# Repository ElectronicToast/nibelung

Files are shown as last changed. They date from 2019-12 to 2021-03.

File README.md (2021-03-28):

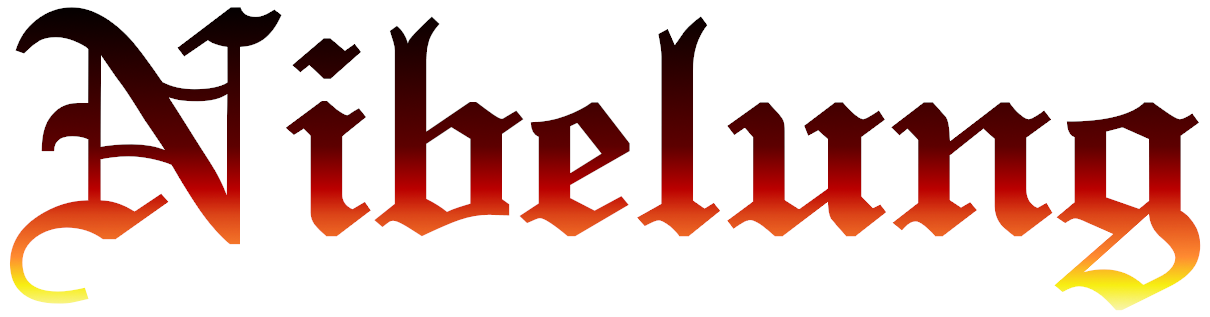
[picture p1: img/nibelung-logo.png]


 

Teensy 4.0-based RGB LED controller

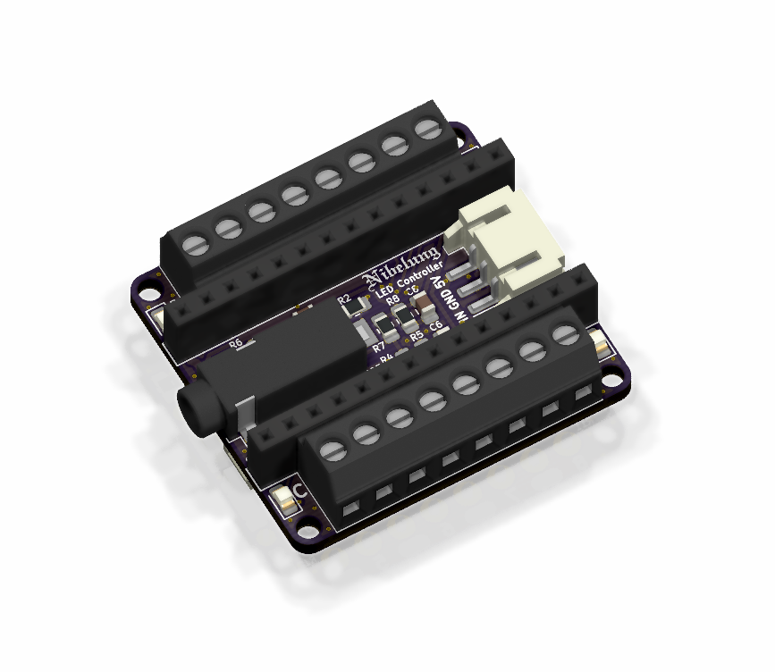
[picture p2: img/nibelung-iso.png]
iso


## Description
Nibelung is a breakout board for the Teensy 4.0 intended for controlling WS2811-based addressable RGB LED strips using the [OctoWS2811 library](https://www.pjrc.com/teensy/td_libs_OctoWS2811.html). Eight LED outputs on Teensy pins 2 to 9 are provided through screw terminals. An audio jack enables music reactive effects with stereo audio through the Teensy's internal ADCs. User pushbuttons and LEDs are provided.

The board is named after the Nibelungen dwarves from Richard Wagner's Ring Cycle.

&nbsp;

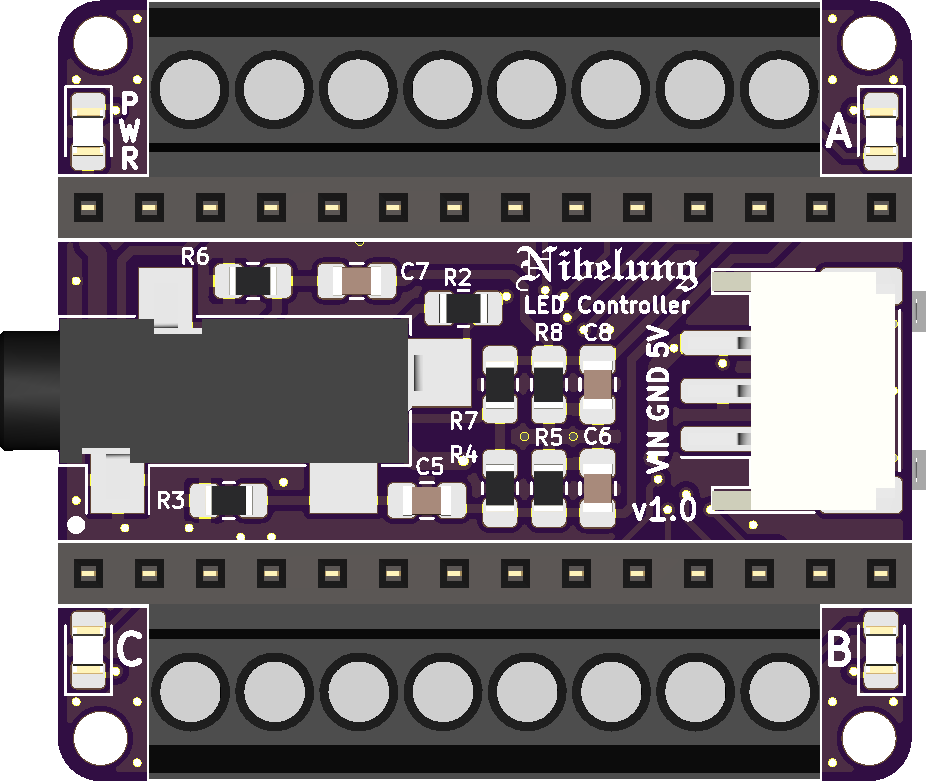
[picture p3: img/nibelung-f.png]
front


&nbsp;

## Usage
Power the board with either USB power through the Teensy or one external power input: 6-12 V (recommended) through `VIN` or regulated 5V through `5V`.

While not designed for Teensy 4.1, the board may be compatible. 

## Licensing
This project is released under the terms of the MIT License.

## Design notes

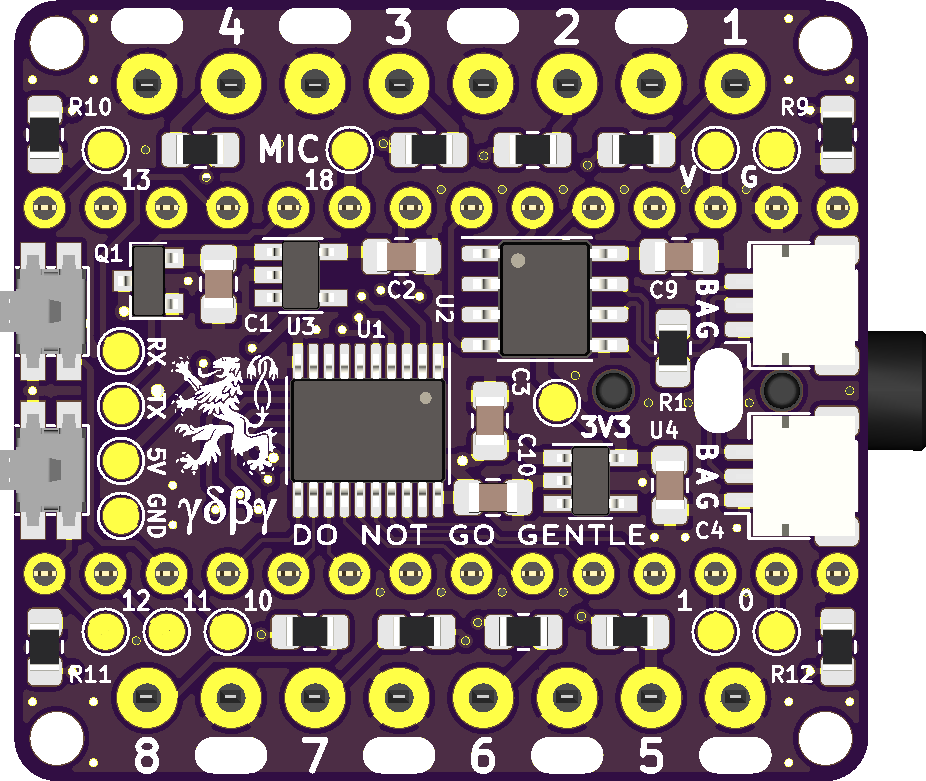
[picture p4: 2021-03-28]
img/nibelung-b.png

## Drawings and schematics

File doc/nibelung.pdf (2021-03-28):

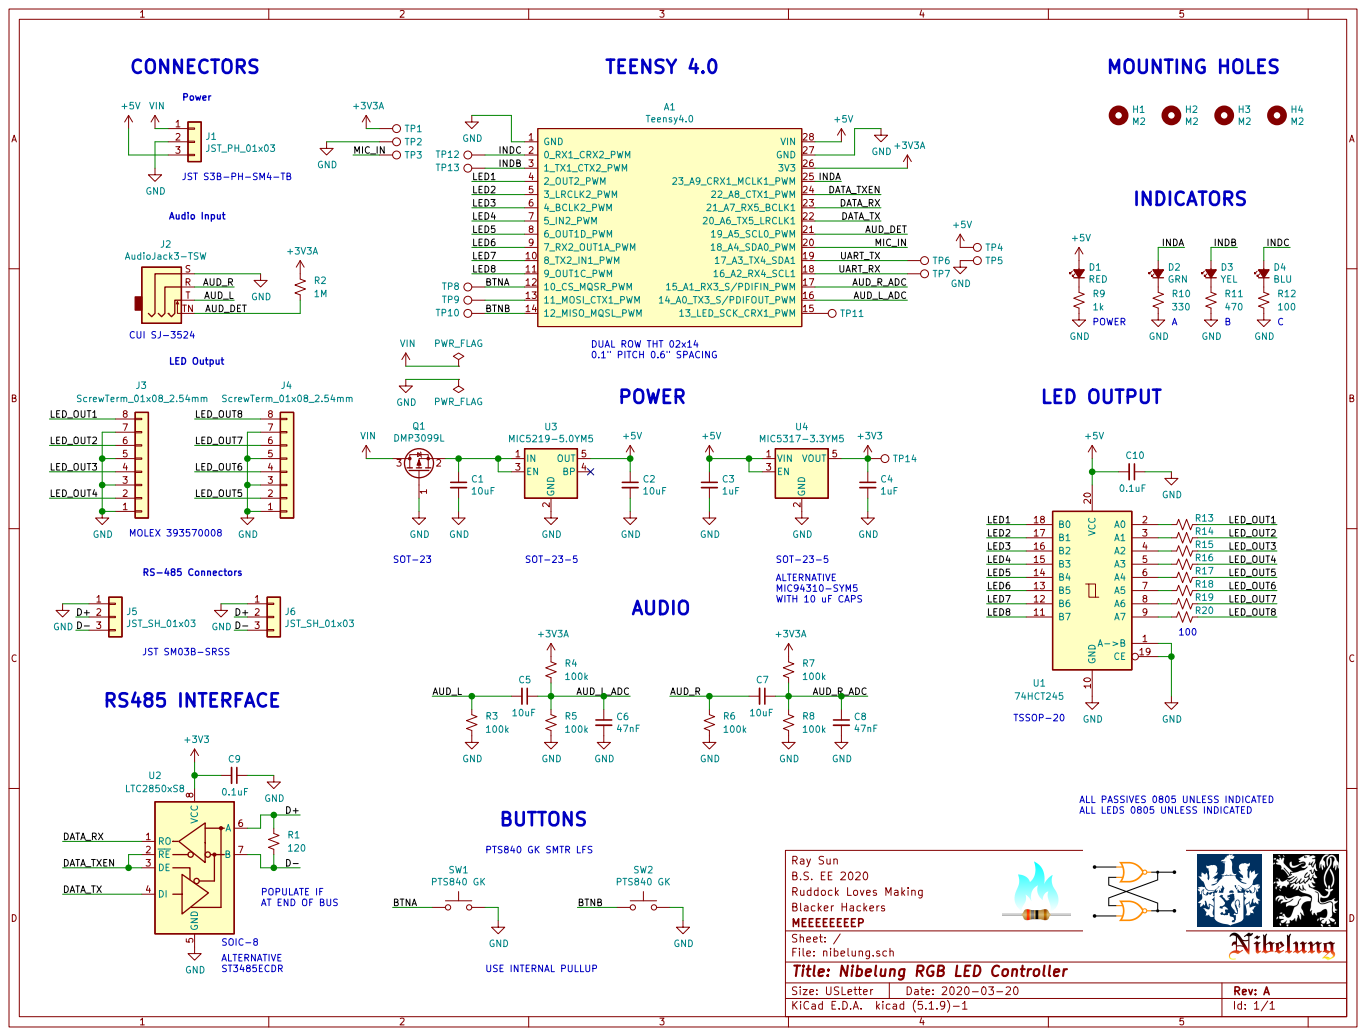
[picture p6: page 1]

2 EN 3 BP 4 OUT 5 U3 MIC5219-5.0YM5 SW1 PTS840 GK

ALTERNATIVE MIC94310-SYM5 WITH 10 uF CAPS

ALL PASSIVES 0805 UNLESS INDICATED
ALL LEDS 0805 UNLESS INDICATED

File: nibelung.sch Sheet: / MEEEEEEEEP

Id: 1/1 Title: Nibelung RGB LED Controller

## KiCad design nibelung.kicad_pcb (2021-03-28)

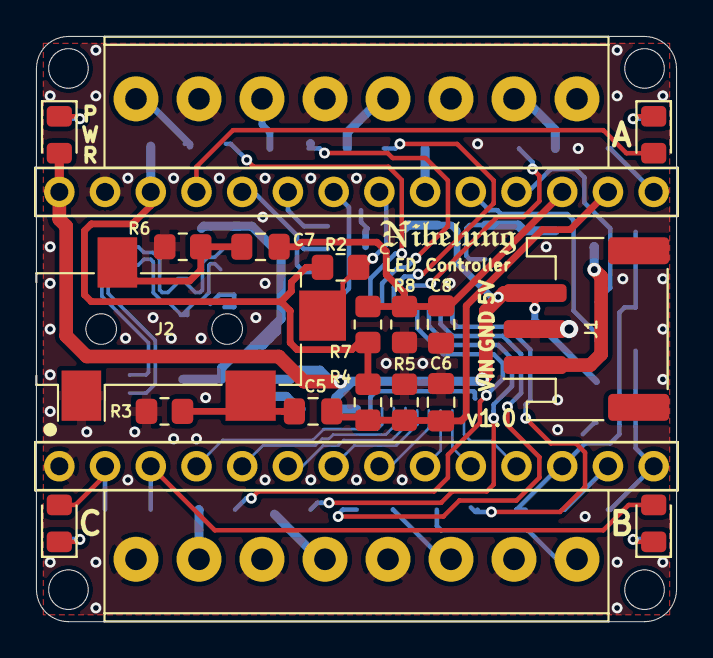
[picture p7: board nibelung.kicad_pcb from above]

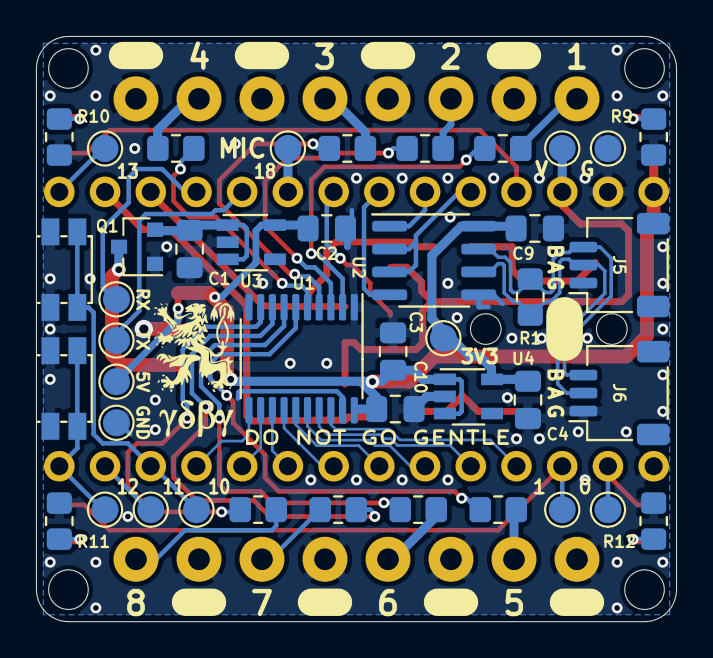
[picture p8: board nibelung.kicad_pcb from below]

Board: 2 copper layers, 35.6 x 32.5 mm, 66 parts (42 on the bottom side), 54 nets.

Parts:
A1: Teensy4.0; Teensy40_Socket
C1, C2, C5, C7: 10uF; C_0805_2012Metric_Pad1.18x1.45mm_HandSolder
C3, C4: 1uF; C_0805_2012Metric_Pad1.18x1.45mm_HandSolder
C6, C8: 47nF; C_0805_2012Metric_Pad1.18x1.45mm_HandSolder
C9, C10: 0.1uF; C_0805_2012Metric_Pad1.18x1.45mm_HandSolder
D1: RED; LED_0805_2012Metric_Pad1.15x1.40mm_HandSolder
D2: GRN; LED_0805_2012Metric_Pad1.15x1.40mm_HandSolder
D3: YEL; LED_0805_2012Metric_Pad1.15x1.40mm_HandSolder
D4: BLU; LED_0805_2012Metric_Pad1.15x1.40mm_HandSolder
H1, H2, H3, H4: M2; MountingHole_2.2mm_M2
J1: JST_PH_01x03; JST_PH_S3B-PH-SM4-TB_1x03-1MP_P2.00mm_Horizontal
J2: AudioJack3-TSW; Jack_CUI_SJ-3524
J3, J4: ScrewTerm_01x08_2.54mm; TerminalBlock_Molex_393570008_1x08_P3.50mm_Horizontal
J5, J6: JST_SH_01x03; JST_SH_SM03B-SRSS-TB_1x03-1MP_P1.00mm_Horizontal
Q1: DMP3099L; SOT-23
R1: 120; R_0805_2012Metric_Pad1.20x1.40mm_HandSolder
R2: 1M; R_0805_2012Metric_Pad1.20x1.40mm_HandSolder
R3, R4, R5, R6, R7, R8: 100k; R_0805_2012Metric_Pad1.20x1.40mm_HandSolder
R9: 1k; R_0805_2012Metric_Pad1.20x1.40mm_HandSolder
R10: 330; R_0805_2012Metric_Pad1.20x1.40mm_HandSolder
R11: 470; R_0805_2012Metric_Pad1.20x1.40mm_HandSolder
R12, R13, R14, R15, R16, R17, R18, R19, R20: 100; R_0805_2012Metric_Pad1.20x1.40mm_HandSolder
SW1, SW2: PTS840 GK; SW_Push_1P1T_NO_CK_PTS840
TP1, TP2, TP3, TP4, TP5, TP6, TP7, TP8, TP9, TP10, TP11, TP12, TP13, TP14: Pad; TestPoint_Pad_D1.5mm
U1: 74HCT245; TSSOP-20_4.4x6.5mm_P0.65mm
U2: LTC2850xS8; SOIC-8_3.9x4.9mm_P1.27mm
U3: MIC5219-5.0YM5; TSOT-23-5
U4: MIC5317-3.3YM5; TSOT-23-5

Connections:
+3V3: C4.1, C9.2, TP14.1, U2.8, U4.5
+3V3A: A1.26, R2.1, R4.1, R7.1, TP1.1
+5V: A1.28, C2.1, C3.1, C10.2, D1.2, J1.3, TP4.1, U1.20, U3.5, U4.1, U4.3
/AUD_DET: A1.21, J2.TN, R2.2
/AUD_L: C5.2, J2.T, R3.1
/AUD_L_ADC: A1.16, C5.1, C6.1, R4.2, R5.1
/AUD_R: C7.2, J2.R, R6.1
/AUD_R_ADC: A1.17, C7.1, C8.1, R7.2, R8.1
/BTNA: A1.12, SW1.2, TP8.1
/BTNB: A1.14, SW2.2, TP10.1
/D+: J5.2, J6.2, R1.1, U2.6
/D-: J5.3, J6.3, R1.2, U2.7
/DATA_RX: A1.23, U2.1
/DATA_TX: A1.22, U2.4
/DATA_TXEN: A1.24, U2.2, U2.3
/INDA: A1.25, D2.2
/INDB: A1.3, D3.2, TP13.1
/INDC: A1.2, D4.2, TP12.1
/LED1: A1.4, U1.18
/LED2: A1.5, U1.17
/LED3: A1.6, U1.16
/LED4: A1.7, U1.15
/LED5: A1.8, U1.14
/LED6: A1.9, U1.13
/LED7: A1.10, U1.12
/LED8: A1.11, U1.11
/LED_OUT1: J3.8, R13.1
/LED_OUT2: J3.6, R14.1
/LED_OUT3: J3.4, R15.1
/LED_OUT4: J3.2, R16.1
/LED_OUT5: J4.2, R17.1
/LED_OUT6: J4.4, R18.1
/LED_OUT7: J4.6, R19.1
/LED_OUT8: J4.8, R20.1
/MIC_IN: A1.20, TP3.1
/UART_RX: A1.18, TP7.1
/UART_TX: A1.19, TP6.1
GND: A1.1, A1.27, C1.2, C2.2, C3.2, C4.2, C6.2, C8.2, C9.1, C10.1, J1.2, J2.S, J3.1, J3.3, J3.5, J3.7, J4.1, J4.3, J4.5, J4.7, J5.1, J6.1, Q1.1, R3.2, R5.2, R6.2, R8.2, R9.2, R10.2, R11.2, R12.2, SW1.1, SW2.1, TP2.1, TP5.1, U1.1, U1.10, U1.19, U2.5, U3.2, U4.2
unnamed: A1.13, TP9.1
unnamed: A1.15, TP11.1
unnamed: C1.1, Q1.2, U3.1, U3.3
unnamed: D1.1, R9.1
unnamed: D2.1, R10.1
unnamed: D3.1, R11.1
unnamed: D4.1, R12.1
unnamed: R13.2, U1.2
unnamed: R14.2, U1.3
unnamed: R15.2, U1.4
unnamed: R16.2, U1.5
unnamed: R17.2, U1.6
unnamed: R18.2, U1.7
unnamed: R19.2, U1.8
unnamed: R20.2, U1.9
VIN: J1.1, Q1.3

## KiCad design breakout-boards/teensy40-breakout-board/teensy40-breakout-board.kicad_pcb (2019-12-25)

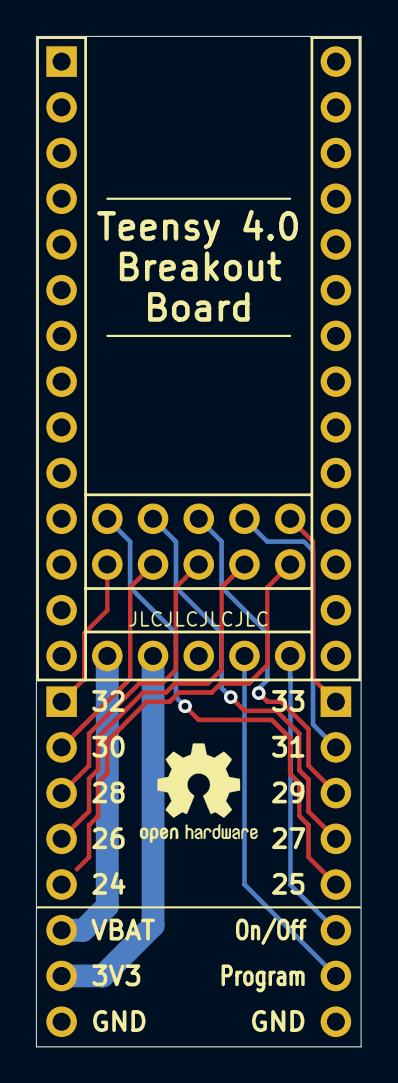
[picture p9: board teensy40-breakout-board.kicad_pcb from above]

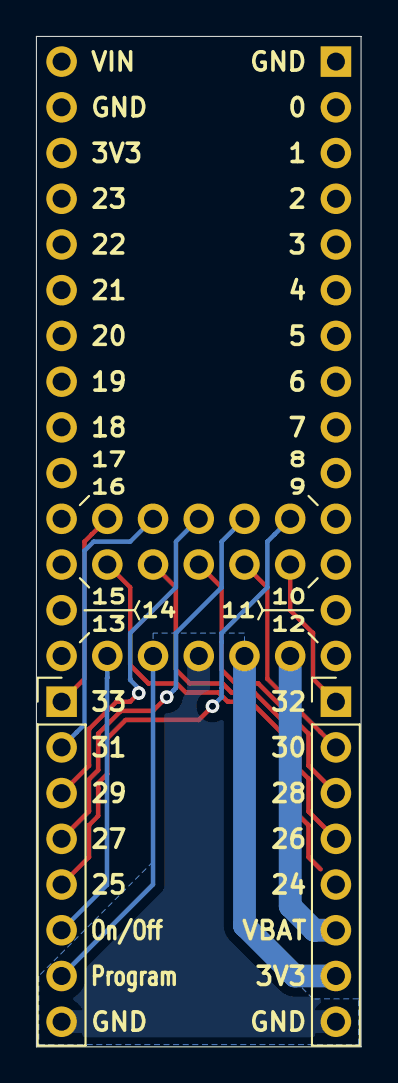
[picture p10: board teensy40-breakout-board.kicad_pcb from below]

Board: 2 copper layers, 18.0 x 56.1 mm, 3 parts (2 on the bottom side), 15 nets.

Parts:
J1, J2: Conn_01x08; PinHeader_1x08_P2.54mm_Vertical
U1: Teensy4.0_WithBottomAndEdge; Teensy40_Socket_WithBottomAndEdge

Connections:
+3V3: J1.7, U1.42
GND: J1.8, J2.8, U1.41
unnamed: J1.1, U1.33
unnamed: J1.2, U1.32
unnamed: J1.3, U1.31
unnamed: J1.4, U1.30
unnamed: J1.5, U1.29
unnamed: J2.1, U1.38
unnamed: J2.2, U1.37
unnamed: J2.3, U1.36
unnamed: J2.4, U1.35
unnamed: J2.5, U1.34
unnamed: J2.6, U1.39
unnamed: J2.7, U1.40
VCC: J1.6, U1.43

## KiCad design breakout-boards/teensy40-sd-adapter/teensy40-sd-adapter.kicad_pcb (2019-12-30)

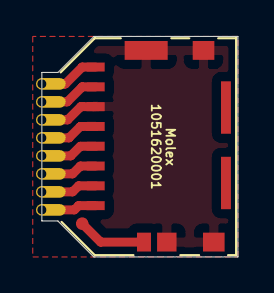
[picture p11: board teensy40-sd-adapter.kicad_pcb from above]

Board: 2 copper layers, 10.9 x 12.2 mm, 3 parts (0 on the bottom side), 9 nets.

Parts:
J1: Micro_SD_Card_Det_Single; microSD_Molex_1051620001
J2: Conn_01x08; Teensy40_SD_Castellated
TP1: TestPoint; Pad_0.7mm

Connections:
/CLK: J1.5, J2.4
/CMD: J1.3, J2.6
/DAT0: J1.7, J2.2
/DAT1: J1.8, J2.1
/DAT2: J1.1, J2.8
/DAT3: J1.2, J2.7
/VDD: J1.4, J2.5
/VSS: J1.6, J1.10, J2.3
unnamed: J1.9, TP1.1

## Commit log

2019-03-31 Add project
    [nibelung.kicad_pcb, nibelung.sch]
2019-07-14 Continue design
    [nibelung.sch]
2019-07-15 Make symbols and footprints
2019-11-08 Add Teensy 4.0 symbol
2019-11-08 Add Teensy 4.0 footprint
2019-11-08 Add schematic backup files to gitignore
2019-11-08 Begin updating schematic to Teensy 4.0
    [nibelung.sch]
2019-11-08 Remove Teensy 3.x artifacts and add pullup to FSYNC
    [nibelung.sch]
2019-12-23 Make additional Teensy 4.0 symbols that break out more of the pins
2019-12-24 Make Teensy 4.0 socket footprints
2019-12-24 Update Teensy 4.0 symbols with corresponding default footprints
2019-12-24 Begin making breakout board for Teensy 4.0
    [teensy40-breakout-board.kicad_pcb, teensy40-breakout-board.sch]
2019-12-25 Complete routing
    [teensy40-breakout-board.kicad_pcb, teensy40-breakout-board.sch]
2019-12-25 Add top silkscreen labels
    [teensy40-breakout-board.kicad_pcb]
2019-12-25 Label all breakout pins
    [teensy40-breakout-board.kicad_pcb]
2019-12-26 Make castellated hole footprint for microSD card adapter board
2019-12-26 Make microSD adapter board; need to select card socket
    [teensy40-sd-adapter.kicad_pcb, teensy40-sd-adapter.sch]
2019-12-26 Add microSD socket symbol
2019-12-26 Fix footprint
2019-12-27 Remove second line of holes
2019-12-27 Break out detect pin for possible prototyping use
    [teensy40-sd-adapter.sch]
2019-12-27 Fix mislabeled ground pin
    [teensy40-sd-adapter.sch]
2019-12-27 Make adapter PCB
    [teensy40-sd-adapter.kicad_pcb]
2019-12-30 Move files and redesign for fab with castellated holes
    [teensy40-sd-adapter.kicad_pcb, teensy40-sd-adapter.sch]
2019-12-30 Generate Gerbers
    [teensy40-sd-adapter-B_Cu.gbl, teensy40-sd-adapter-B_Mask.gbs, teensy40-sd-adapter-B_SilkS.gbo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]
2019-12-30 Make adapter with a Arduino HC-05 programming adapter board for panel production
    [hc05-adapter.sch, teensy40-bb-hc05-adapter.kicad_pcb, teensy40-bb-hc05-adapter.sch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]
2019-12-31 Revise routing
    [teensy40-bb-hc05-adapter.kicad_pcb]
2019-12-31 Clean up positions
    [teensy40-bb-hc05-adapter.kicad_pcb]
2019-12-31 Clean up more
    [teensy40-bb-hc05-adapter.kicad_pcb]
2019-12-31 Add more silkscreen labels
    [teensy40-bb-hc05-adapter.kicad_pcb]
2019-12-31 Prepare for paneling
    [teensy40-bb-hc05-adapter.kicad_pcb]
2019-12-31 Make panel
    [teensy40-bb-hc05-adapter.kicad_pcb]
2019-12-31 Finish panel
    [teensy40-bb-hc05-adapter.kicad_pcb]
2019-12-31 Put edge and Vccut on same Gerber file
    [teensy40-bb-hc05-adapter-B_Cu.gbl, teensy40-bb-hc05-adapter-B_Mask.gbs, teensy40-bb-hc05-adapter-B_SilkS.gbo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]
2019-12-31 Add separate panels
    [hc05-adapter-panel-B_Cu.gbl, hc05-adapter-panel-B_Mask.gbs, hc05-adapter-panel-B_SilkS.gbo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]
2019-12-31 Move edge rail to make less than 100mm long
    [hc05-adapter-panel-B_Cu.gbl, hc05-adapter-panel-B_Mask.gbs, hc05-adapter-panel-B_SilkS.gbo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]
2019-12-31 Rename edge and Vcut file
    [hc05-adapter-panel-Edge_Vcut.gm1]
2020-12-25 Move breakout board projects
    [hc05-adapter-panel-B_Cu.gbl, hc05-adapter-panel-B_Mask.gbs, hc05-adapter-panel-B_SilkS.gbo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]
2020-12-25 Begin redesign
    [nibelung.sch]
2020-12-26 Edit sheet layout
    [nibelung.sch]
2020-12-26 Add terminal block footprints
2020-12-27 Add 8 pin terminal block and update descriptions
2021-01-02 Add most connectors and RS-485 transceiver
    [nibelung.sch]
2021-01-02 Modify audio circuit to typical cap coupling topology
    [nibelung.sch]
2021-01-02 Set up design rules
    [nibelung.kicad_pcb]
2021-01-02 Begin preliminary placement
    [nibelung.kicad_pcb, nibelung.sch]
2021-01-03 Add power connectors
    [nibelung.kicad_pcb, nibelung.sch]
2021-01-03 Add 2.54mm screw terminal
2021-01-03 Adjust for M2.5 mounting holes
    [nibelung.kicad_pcb, nibelung.sch]
2021-01-04 Add indicator LEDs
    [nibelung.kicad_pcb, nibelung.sch]
2021-01-04 Swap power and RS-485 connector locations
    [nibelung.kicad_pcb]
2021-01-04 Revise placement and label output connections
    [nibelung.kicad_pcb, nibelung.sch]
2021-01-04 Replace 2-pin PH power connector with 3-pin PH
    [nibelung.kicad_pcb, nibelung.sch]
2021-01-09 Add linear regulators
    [nibelung.kicad_pcb, nibelung.sch]
2021-01-09 Add right angle pushbuttons
    [nibelung.kicad_pcb, nibelung.sch]
2021-01-15 Continue placement
    [nibelung.kicad_pcb, nibelung.sch]
2021-01-16 Length-match differential pair traces
    [nibelung.kicad_pcb]
2021-01-16 Replace 2.54mm pitch terminals with 3.5mm pitch ones
    [nibelung.kicad_pcb, nibelung.sch]
2021-01-17 Make board less wide
    [nibelung.kicad_pcb, nibelung.sch]
2021-01-18 Add properly colored STEP models
    [nibelung.kicad_pcb, nibelung.sch]
2021-03-28 Finish layout
    [nibelung-B_Cu.gbl, nibelung-B_Mask.gbs, nibelung-B_SilkS.gbo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]
2021-03-28 Clean up via holes to minimize interrupting silkscreen
    [nibelung.kicad_pcb]
